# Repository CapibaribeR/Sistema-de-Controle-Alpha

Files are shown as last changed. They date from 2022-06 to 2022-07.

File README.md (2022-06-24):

Logo Capibax
# Sistema de Controle Alpha Motor Scooter

- Área: **Elétrica**
- Subárea: **Powertrain**
- Responsável:
  - **Nathan Pinheiro, nathan.pinheiro@ufpe.br**
- Período de trabalho: **23/06/2022~~xx/xx/xxxx**
- Link para pasta no drive: **[Sistema de Controle do Motor](https://drive.google.com/drive/u/0/folders/1gA4DVZMdsN3olOmKE0vOmF9ez8T_oJ0C)**

## Objetivos

O sistema de controle Alpha é o mais simples sistema de controle dos motores e inversores pela DCU, unidade de controle dinâmica do veículo. O sistema Alpha 
recebe dados de 2 sensores que medem o deslocamente do pedal do acelerador (APPS) e de um sensor que mede o deslocamento do pedal do freio (BSE). Mediante os
dados recebidos e uma lógica de controle, o sistema Alpha deve mandar a requisitada velocidade que o piloto está pedindo (ao pressionar o pedal) para o inversor,
este responsável por então ajustar o motor para a velocidade desejada. O diagrama abaixo representa a visão geral do sistema de controle alpha.
Diagrama de Blocos Hardware

## Desenvolvimento

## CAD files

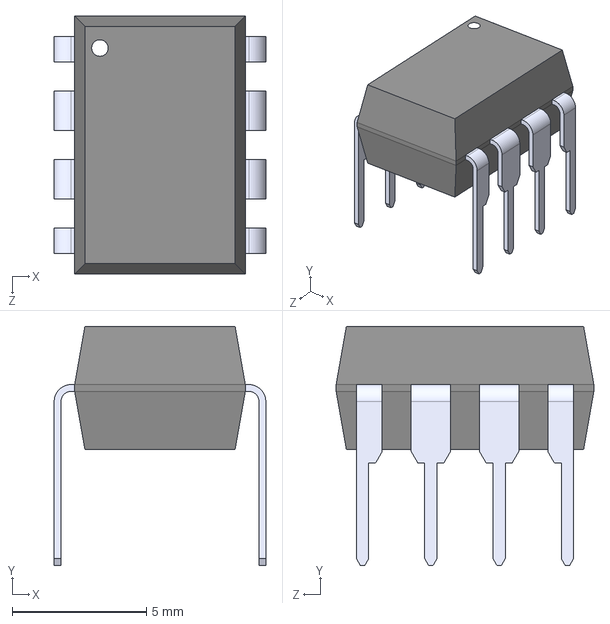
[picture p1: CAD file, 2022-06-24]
Esquematico/APPS+Sistema de Controle3/Footprints/LM358P/LM358P.step
7.87 x 8.89 x 9.59 mm

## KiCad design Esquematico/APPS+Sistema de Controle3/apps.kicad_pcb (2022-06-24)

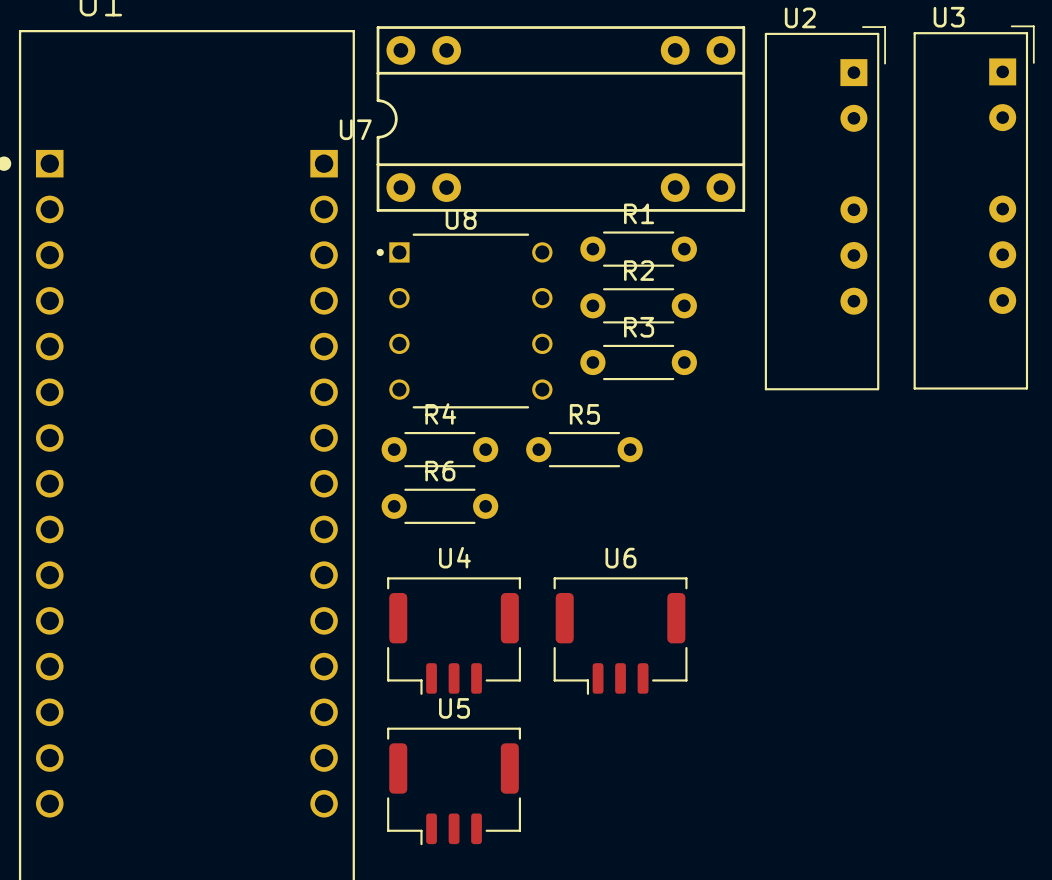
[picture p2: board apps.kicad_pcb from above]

Board: 2 copper layers, 14 parts (0 on the bottom side), 7 nets, no tracks yet.

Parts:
R1, R3, R5: 22k; R_Axial_DIN0204_L3.6mm_D1.6mm_P5.08mm_Horizontal
R2, R4, R6: 100k; R_Axial_DIN0204_L3.6mm_D1.6mm_P5.08mm_Horizontal
U1: STM32F303K8; MODULE_NUCLEO-F303K8
U2, U3: A0515S-2W; Converter_DCDC_muRata_NMAxxxxSC_THT
U4, U6: RTY120LVNAX; Molex_CLIK-Mate_502382-0370_1x03-1MP_P1.25mm_Vertical
U5: Inversor; Molex_CLIK-Mate_502382-0370_1x03-1MP_P1.25mm_Vertical
U7: ISO124; 8
U8: LM358P; DIP794W45P254L959H508Q8

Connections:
/+5V: U4.1, U6.1
/S1_APPS: R1.1, R2.2
/S2_APPS: R3.1, R4.2
GND: R2.1, R4.1, U4.2, U6.2
unnamed: R1.2, U4.3
unnamed: R3.2, U6.3
unnamed: R5.2, R6.2

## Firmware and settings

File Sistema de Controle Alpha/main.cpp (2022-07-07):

/* Bibliotecas */
#include "mbed.h"


/* Pinagem */
#define sensor_apps1  PA_5                           // Sinal de entrada do sensor do apps 1
#define sensor_apps2  PA_6                           // Sinal de entrada do sensor do apps 2
#define sensor_bse    PF_4                           // Sinal de entrada do sensor do bse
#define pino_inversor PA_4                           // Sinal de saída para o inversor


/* Adicionar o timer de maneira legível */
#define timer_read_ms(x)    chrono::duration_cast<chrono::milliseconds>((x).elapsed_time()).count()


/* Estrutura de dados */
typedef enum {CHECK, FALHA, TORQUE} state;


/* Classes API */
AnalogOut inversor_envio(pino_inversor);
AnalogIn apps1_aq(sensor_apps1);
AnalogIn apps2_aq(sensor_apps2);
AnalogIn bse_aq(sensor_bse);
Timer tempo_erro;
//InterruptIn bse_aq(sensor_bse);


/* Variaveis */
// Variaveis para a medicao de falha
bool  flag_plausibility = 0;
bool  flag_falha_sensores = 0;
float inversor;
float apps1;
float apps2;
float bse;

//Declaraveis
float max_apps1 = 3.33;                              // Sinal máximo do sensor 1 do APPS
float min_apps1 = 0.37;                              // Sinal minimo do sensor 1 do APPS
float max_apps2 = 3.33;                              // Sinal máximo do sensor 2 do APPS
float min_apps2 = 0.37;                              // Sinal minimo do sensor 2 do APPS
float max_bse = 2.93;                                // Sinal maximo do sensor do BSE
float min_bse = 0.73;                                // Sinal minimo do sensor do BSE

//Maquina de estados
state estado = TORQUE;                               // Variavel para o controle da maq de estados


/* Declaracao das funcoes */
void convertevalores();
void verifica_falha_sensores();
void freio_plausibility_check();


/* Função Main */
int main() {

    //Setando as tensoes de referencia para o ADC
    apps1_aq.set_reference_voltage(3.3);
    apps2_aq.set_reference_voltage(3.3);
    bse_aq.set_reference_voltage(3.3);

    while (true) {

        convertevalores();
        verifica_falha_sensores();
        freio_plausibility_check();
        /* Maquina de estados */
        switch (estado) {

            case CHECK:
                tempo_erro.start();
                if(timer_read_ms(tempo_erro) > 100) {
                    printf("%llu \n", timer_read_ms(tempo_erro));
                    estado = FALHA;
                    tempo_erro.stop(); 
                    tempo_erro.reset();
                } else {
                    estado = TORQUE;
                }
                break;

            case FALHA:
                inversor_envio.write(0);
                printf("Dentro da FALHA, mandando 0V \n");
                break;

            case TORQUE:
                inversor_envio.write(apps1);
                //printf("Valor percentual do apps1: %f \n", inversor_envio.read_volt());
                printf("Enviando %f de tensao \n", inversor_envio.read()*3.3);
                break;
        }
    }
}


/* Corpo das funcoes */
// Funcao responsavel para mapear os valores dos 2 sensores do apps
void convertevalores () {
    apps1 = (apps1_aq.read_voltage() - min_apps1) / (max_apps1 - min_apps1);
    apps2 = (apps2_aq.read_voltage() - min_apps2) / (max_apps2 - min_apps2);
    bse =   (bse_aq.read_voltage() - min_bse)     / (max_bse - min_bse);
}


//Funcao responsavel por detectar se ha algum erro das medicoes dos 3 sensores e disparidade dos 2 apps
void verifica_falha_sensores() {

    //printf("Apps1 = %f e Apps2 = %f \n", apps1_aq.read_voltage(), apps2_aq.read_voltage());
    if ( (apps1 > (1.1*apps2)) || (apps1 < (0.9*apps2)) ) {
        printf("Erro de 10 porcento entre os sensores, %f e %f \n", apps1_aq.read_voltage(), apps2_aq.read_voltage());
        //estado = CHECK; 
        flag_falha_sensores = 1;
    }
    else {
        if ( (apps1_aq.read_voltage() > max_apps1) ) {
            printf("Apps1 acima da escala maxima, %f e %f \n", apps1_aq.read_voltage(), apps2_aq.read_voltage());
            //estado = CHECK;
            flag_falha_sensores = 1;
        }
        else {
            if( (apps2_aq.read_voltage() > max_apps2) ) {
                printf("Apps2 acima da escala maxima, %f e %f \n", apps1_aq.read_voltage(), apps2_aq.read_voltage());
                //estado = CHECK;
                flag_falha_sensores = 1;
            }
            else {
                if  (apps1_aq.read_voltage() < min_apps1 ) {
                    printf ("Apps1 abixo da escala minima, %f e %f \n", apps1_aq.read_voltage(), apps2_aq.read_voltage());
                    //estado = CHECK;
                    flag_falha_sensores = 1;
                }
                else {
                    if (apps2_aq.read_voltage() < min_apps2) {
                        printf("Apps2 abaixo da escala minima, %f e %f \n", apps1_aq.read_voltage(), apps2_aq.read_voltage());
                        //estado = CHECK;
                        flag_falha_sensores = 1;
                    }
                    else {
                        if(bse_aq.read_voltage() > max_bse) {
                            printf("BSE acima da escala maxima, %f \n", bse_aq.read_voltage());
                            //estado = CHECK;
                            flag_falha_sensores = 1;
                        }
                        else {
                            if(bse_aq.read_voltage() < min_bse) {
                                printf("BSE abaixo da escala minima, %f \n", bse_aq.read_voltage());
                                //estado = CHECK;
                                flag_falha_sensores = 1;
                            }
                            else {
                                estado = TORQUE;
                                flag_falha_sensores = 0;
                            }
                        }
                    }
                }
            }
        }
    }

    if(flag_falha_sensores == 1) {
        tempo_erro.start();
        if(timer_read_ms(tempo_erro) > 100) {
            printf("%llu \n", timer_read_ms(tempo_erro));
            estado = FALHA;
            tempo_erro.stop(); 
            tempo_erro.reset();
            }
    } else {
        tempo_erro.stop(); 
        tempo_erro.reset();
    }
}


//Funcao responsavel por identificar se ha presença de pressionamento de freio e pedal simultaneos
void freio_plausibility_check() {
    if((apps1 > 0.25) && (bse > 0.1) && (flag_plausibility == 0)) {
        estado = FALHA;
        flag_plausibility = 1;
        printf("Erro plausibility check \n");
    } else {
        if((flag_plausibility == 1) && (apps1 < 0.05)) {
            printf("FALHA DE PLAUSIBILIDADE \n");
            estado = TORQUE;
            flag_plausibility = 0;
        }
    }
}

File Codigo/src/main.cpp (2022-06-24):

/* Bibliotecas */
#include "mbed.h"


/* Pinagem */
#define sensor_apps1  PA_5                          // Sinal de entrada do sensor do apps 1
#define sensor_apps2  PA_6                          // Sinal de entrada do sensor do apps 2
#define sensor_bse    PB_0                          // Sinal de entrada do sensor do bse
#define pino_inversor PA_4                          // Sinal de saída para o inversor //Isso


/* Estrutura de dados */
typedef enum {FALHA, TORQUE} state;


/* Classes API */
AnalogIn apps1_aq(sensor_apps1);
AnalogIn apps2_aq(sensor_apps2);
AnalogIn bse_aq(sensor_bse);
AnalogOut inversor_envio(pino_inversor);


/* Variaveis */
// Variaveis para a medicao de erro
bool flag_falha;
float apps1;
float apps2;
float bse;
float inversor;

//Declaraveis
float max_apps1;
float min_apps1;
float max_apps2;
float min_apps2; 

//Maquina de estados
state estado;

/* Funcoes */
void convertevalores();
int funcao_falha();


int main()
{
    while (true) {
        switch (estado) {

            case FALHA:
                inversor_envio.write(0);
                break;

            case TORQUE:
                inversor_envio.write(apps1);
                printf("Enviando %f de tensao", apps1_aq.read_voltage());
                break;
        }
    }
}

 
void convertevalores () {
    /*
    apps1 = apps1_aq.read_voltage();
    apps2 = apps2_aq.read_voltage();
    bse = bse_aq.read_voltage();
    */
    //Valores convertidos em porcentagem
    apps1 = (apps1_aq.read_voltage() - min_apps1) / (max_apps1 - min_apps1);
    apps2 = (apps2_aq.read_voltage() - min_apps2) / (max_apps2 - min_apps2);
}


int funcao_falha() {
    convertevalores();
    if ( (apps1 > (0.1*apps2)) || (apps1 < (0.1*apps2)) ) {
        printf("Erro de 10 porcento entre os sensores, %f e %f \n", apps1_aq.read(), apps2_aq.read_voltage());
        return 0;
    }
    else {
        if ( (apps1 > max_apps1) ) {
            printf("Apps1 acima da escala maxima, %f e %f \n", apps1_aq.read(), apps2_aq.read_voltage());
            return 0;
        }
        else {
            if( (apps2 > max_apps2) ) {
                printf("Apps2 acima da escala maxima, %f e %f \n", apps1_aq.read(), apps2_aq.read_voltage());
                return 0;
            }
            else {
                if  (apps1 < min_apps1 ) {
                    printf ("Apps1 abixo da escala minima, %f e %f \n", apps1_aq.read(), apps2_aq.read_voltage());
                    return 0;
                }
                else {
                    if (apps2 < min_apps2) {
                        printf("Apps2 abaixo da escala minima, %f e %f \n", apps1_aq.read(), apps2_aq.read_voltage());
                        return 0;
                    }
                    else {
                                return 1;
                    }
                }
            }
        }
    }
}

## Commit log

2022-06-24 Primeiro commit
    [LM358P.step, apps.kicad_pcb, apps.sch]
2022-06-24 Adição do código no PlatformIO
    [LM358P.step, apps.kicad_pcb, apps.sch]
2022-06-27 Adicionando uma nova versão do código
    A pasta de sistema de controle que é onde está o código real feito no MBED
2022-06-29 Pinagem do sensor bse
2022-07-06 Analise de erro resolvida
2022-07-07 Resolvido ERROR, resolvendo plausibility
    [main.cpp]
